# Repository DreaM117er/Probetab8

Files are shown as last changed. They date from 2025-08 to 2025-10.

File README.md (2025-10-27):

# Probetab8

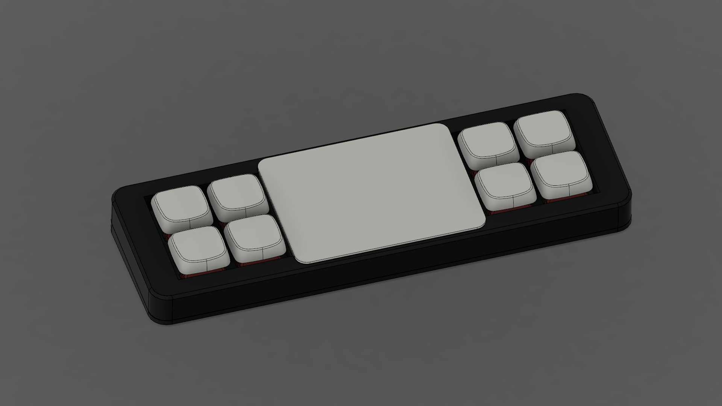
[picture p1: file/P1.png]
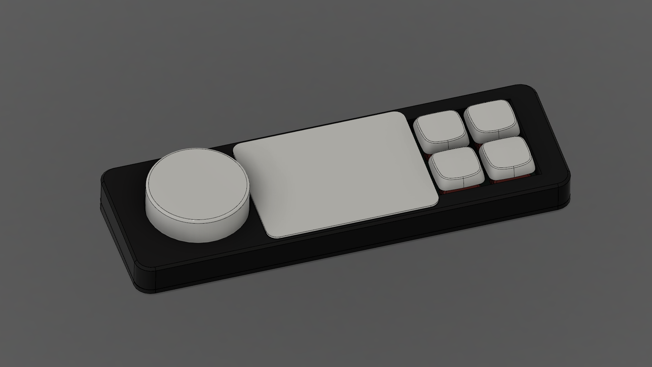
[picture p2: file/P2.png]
|||
|--|--|
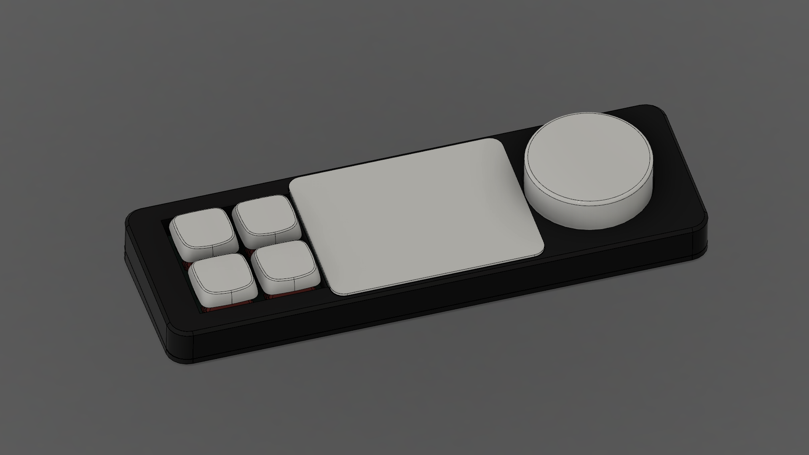
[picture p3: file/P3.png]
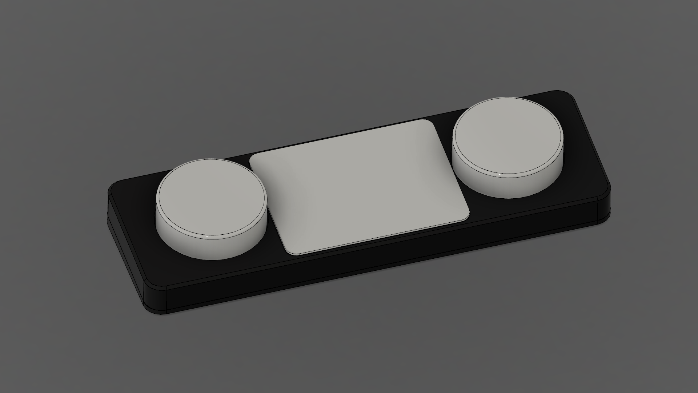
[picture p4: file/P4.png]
|||

## 說明

Probetab8是一把在設計途中不斷地向Google Gemini諮詢電路學知識的一把迷你鍵盤，是我用來進一步地學習電路學的一個巨大突破的成果。

這把鍵盤有以下幾個特點：
1. 晶片核心爲RP2040，全引腳輸出。
2. 可以燒錄RP2040 Debug Probe官方的韌體。
3. 可以按照我設計的佈局設置需要的功能：4+4顆按鍵、4按鍵+1旋鈕、2旋鈕。
4. 搭載Azoteq TPS65觸控板。
5. QMK/VIAL韌體。

## 使用材料

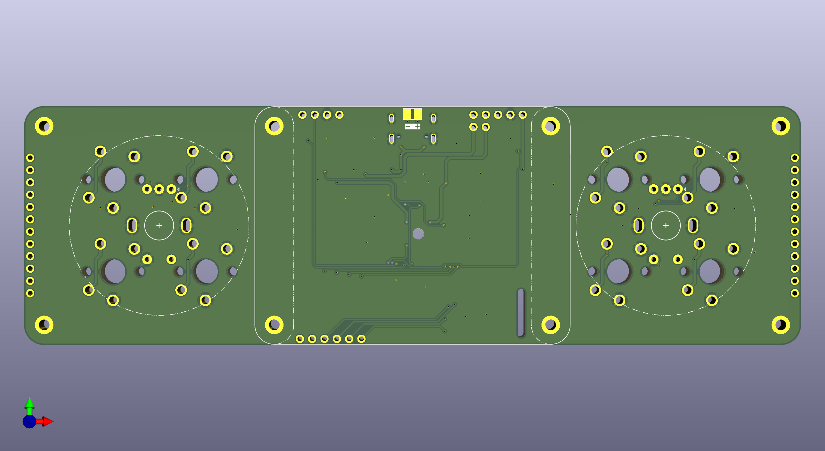
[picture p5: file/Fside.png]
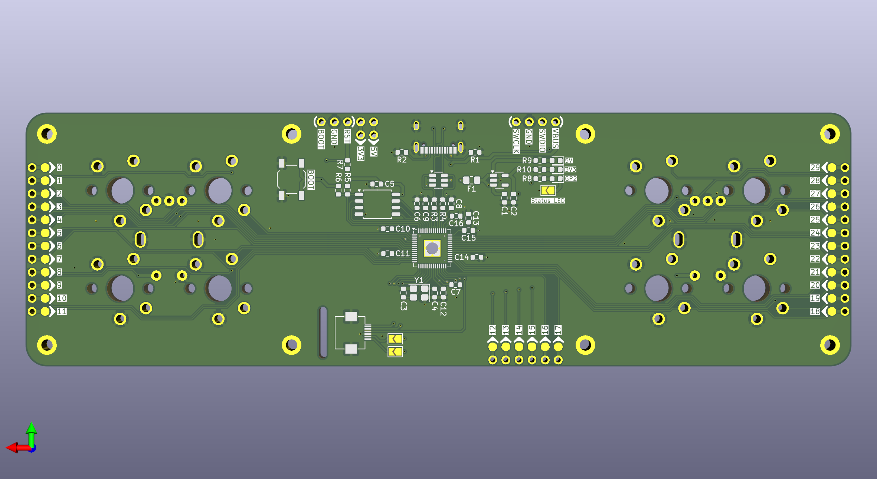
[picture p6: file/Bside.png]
|||
|--|--|

### 電子元件

|類型|名稱|數量|封裝|備註|Reference|
|--|--|--|--|--|--|
|MCU|RP2040|1|QFN-56|-|U3|
|ESD|SRV05-4|1|SOT-23-6|-|U1|
|LDO|RT9013-33GB|1|SOT-23-5|-|U2|
|QSPI|W25Q128JVS|1|SOIC-8|-|U4|
|Resonator|Crystal|1|SMD-3225-4Pin|-|Y1|
|Receptacle|USB-C|1|-|16Pin|-|
|Fuse|6V, 500mA|1|0805|-|F1|
|SW|-|1|SPST_TL3342|BOOT||
|Capacitor|1uF|4|0603|-|C1, C2, C8, C16|
|Capacitor|15pF|2|0603|-|C3, C4|
|Capacitor|100nF|10|0603|-|C5-C7, C9-C15|
|Resistor|5.1K|2|0603|-|R1, R2|
|Resistor|27R|2|0603|-|R3, R4|
|Resistor|10K|2|0603|-|R5, R7|
|Resistor|1K|1|0603|-|R6|
|Resistor|470R|2|0603|-|R8, R9|
|Resistor|220R|1|0603|-|R10|
|Module|TPS65-201A-S|1|-|-|-|
|Cable|FFC-0.5mm|1|6Pin|L: 100mm|-|
|Socket|FFC-0.5mm|1|FH12-6S-0.5SH 6Pin|-|-|
|RED|LED|3|0603|After R8-10|-|

### 機構元件

|名稱|規格|數量|備註|
|--|--|--|--|
|Screw|M2x4mm|4|扁頭|
|Screw|M2x6mm|2|扁頭|
|Screw|M2x8mm|2|扁頭|
|Case|上蓋|1|-|
|Case|下蓋|1|-|
|Feets|8x1mm|4|矽膠腳貼|

### 自由選擇

|名稱|規格|數量|備註|
|--|--|--|--|
|按鍵|Choc v1, GLP1.0-2.0|0-8|-|
|鍵帽|Choc v1, MX stem for LP|0-8|-|
|編碼器|EC-11|0-2|L: 10mm、A: 5.5-5.0mm, 半軸 D型|

## 注意事項

- 不提供CSV給大家使用，如果需要PCBA，請自行修改PCB檔案。因爲這把鍵盤屬於純手工焊接，挑戰自己的焊接技巧，成果就是你的。
- 外殼上蓋有分4種，分別應對自由選擇的元件使用，底殼通用。
- 外殼檔案及PCB檔案都開放給大家，要修正改造請按照開源相關規定，我就不再說明了。 
- 焊接的時候，特別注意預熱、加熱相關的技巧及熟悉度，以免燒壞MCU或是燙傷；還有注意環境通風。
- 關於Jumper：

    - Status LED：測試燈開關，測試沒問題可移除。
    - TPS65模組：RDY及RST，有使用這兩個引腳再焊接。

## 軟體工具

- Fusion。
- KiCAD 9.0.2。
- VScode。
- QMK、VIAL。
- Resberry官方Debug Probe韌體。

## 硬體工具

- TS-100、TS-101。
- MPH-30。
- FDM列印機。
- 萬用電表。

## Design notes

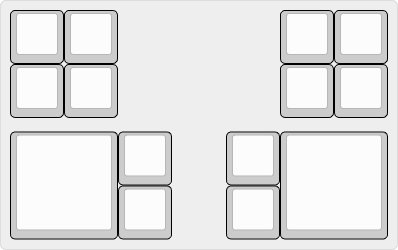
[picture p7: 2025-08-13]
file/Layout.png

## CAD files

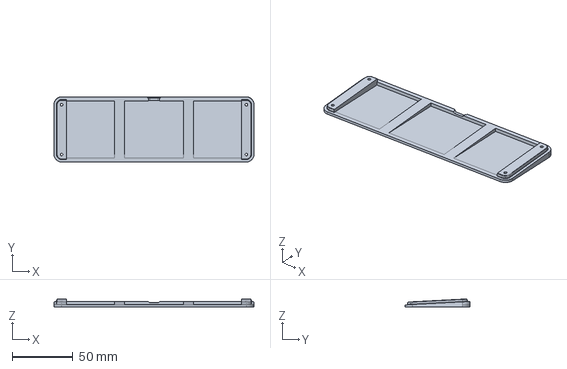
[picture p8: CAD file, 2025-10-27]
case/Bottom.step
164.4 x 53.4 x 6.69 mm

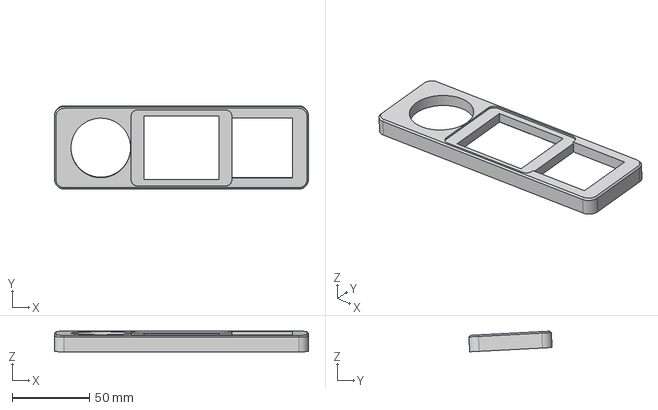
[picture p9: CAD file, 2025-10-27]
case/1x4keys.step
164.4 x 53.9 x 13.4 mm

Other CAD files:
case/4x2keys.step
case/1x1keys.step
case/4x1keys.step

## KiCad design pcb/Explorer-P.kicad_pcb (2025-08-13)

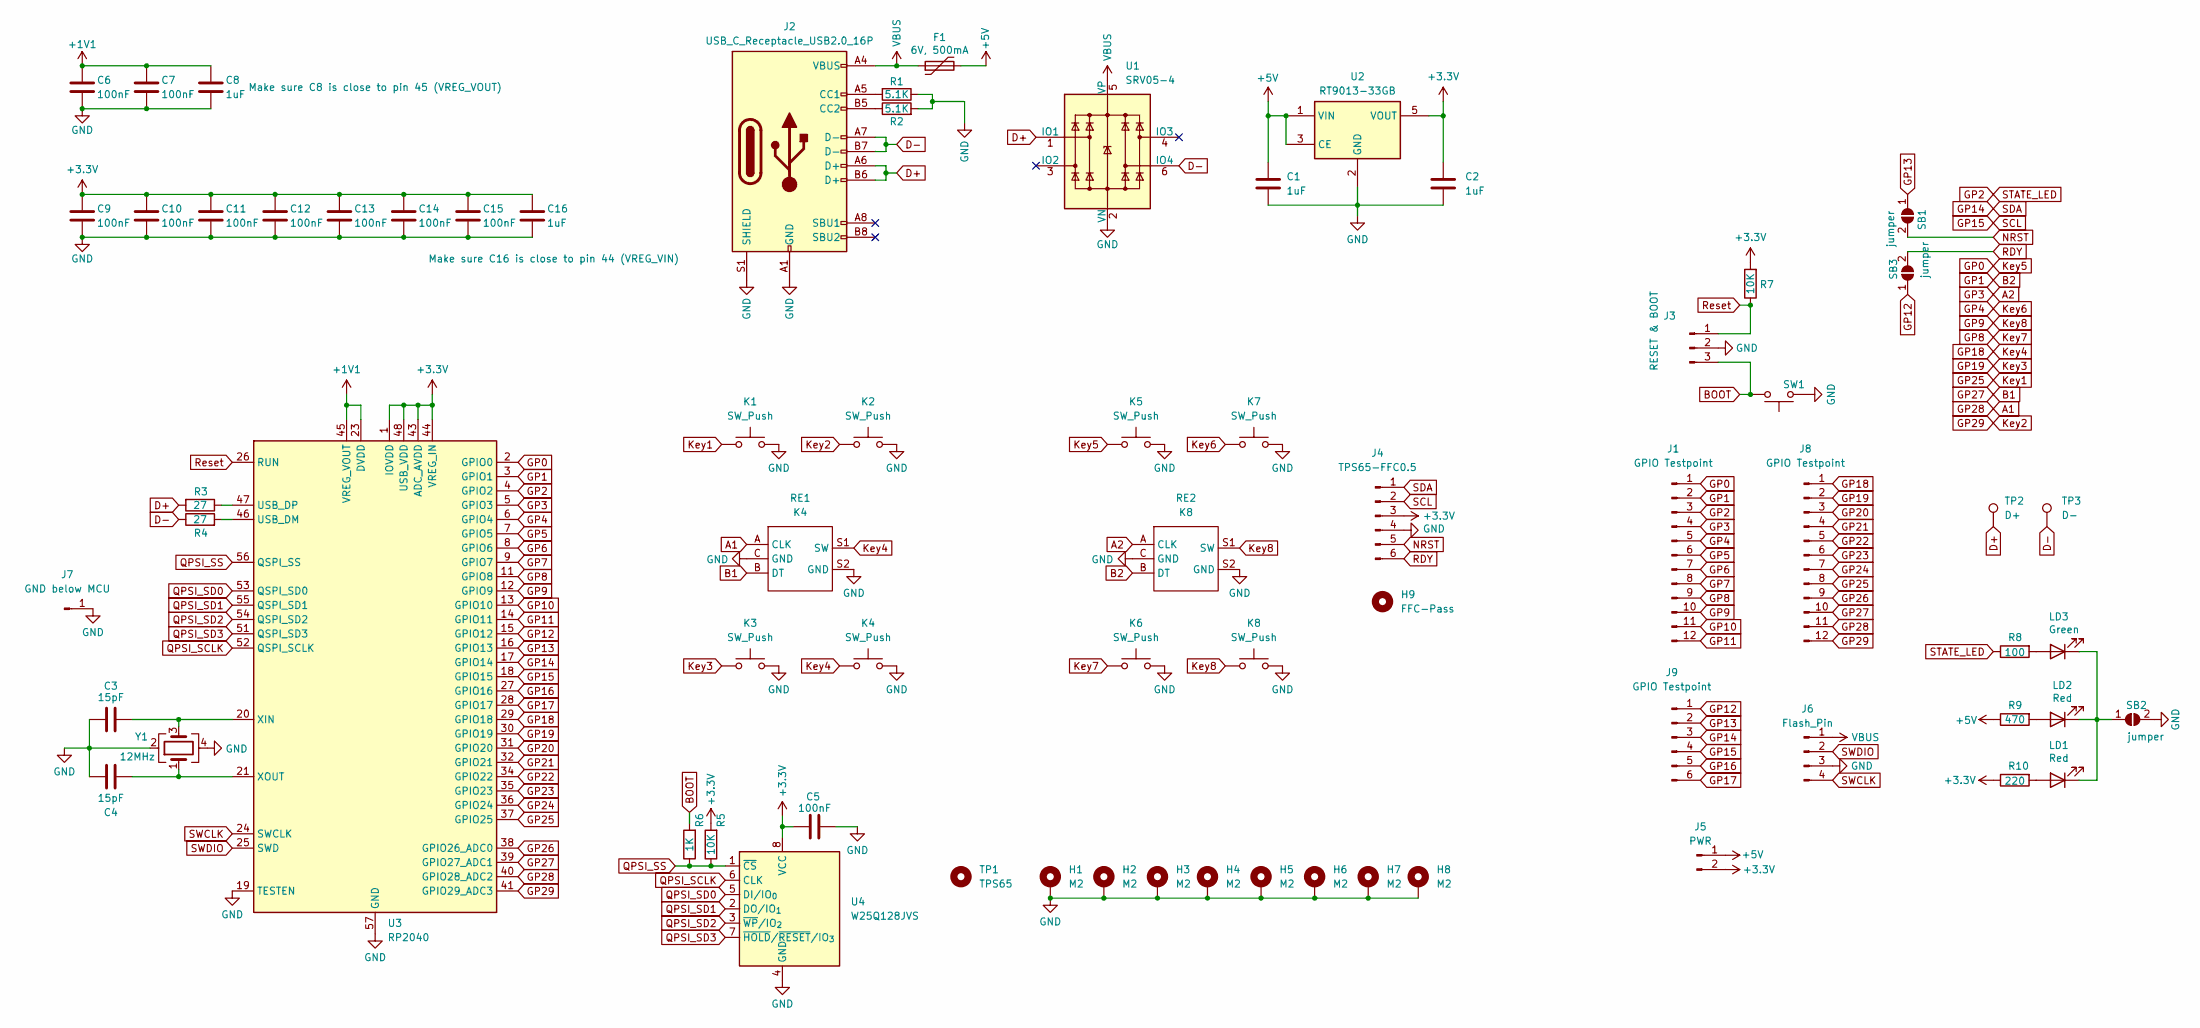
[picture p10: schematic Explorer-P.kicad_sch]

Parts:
C1, C2: 1uF; R_0603_1608Metric
C3, C4: 15pF; R_0603_1608Metric
C5: 100nF; R_0603_1608Metric
C6, C7, C9, C10, C11, C12, C13, C14, C15: 100nF; R_0603_1608Metric; MFR. Part # CL05B104KB54PNC
C8, C16: 1uF; R_0603_1608Metric; MFR. Part # CL05A105KA5NQNC
F1: 6V, 500mA; C_0805_2012Metric_Pad1.18x1.45mm_HandSolder; LCSC C269104
H1, H2, H3, H4, H5, H6, H7, H8: M2; MountingHole_2.2mm_M2_DIN965_Pad
H9: FFC-Pass; MountingHole_2.2mm_M2
J1, J8: GPIO Testpoint; Testpoint_2.54mm_01x12_1to2_Hole2Pad
J2: USB_C_Receptacle_USB2.0_16P; USB_C_Receptacle_G-Switch_GT-USB-7010ASV
J3: RESET & BOOT; PinHeader_1x03_P2.54mm_Vertical
J4: TPS65-FFC0.5; Hirose_FH12-6S-0.5SH_1x06-1MP_P0.50mm_Horizontal
J5: PWR; Testpoint_2.54mm_01x02_1to2_Hole2Pad
J6: Flash_Pin; PinHeader_1x04_P2.54mm_Vertical
J7: GND below MCU; MountingHole_2.2mm_M2_DIN965_Pad
J9: GPIO Testpoint; Testpoint_2.54mm_01x06_1to2_Hole2Pad
K1, K2, K3, K4, K5, K6, K7, K8: SW_Push; SW_Choc_GLP_KLP12_THT2
LD1, LD2: Red; LED_0603_1608Metric; MFR. Part # 19-217/GHC-YR1S2/3T; LCSC C72043
LD3: Green; LED_0603_1608Metric; MFR. Part # 19-217/GHC-YR1S2/3T; LCSC C72043
R1, R2: 5.1K; R_0603_1608Metric
R3, R4: 27; R_0603_1608Metric
R5, R7: 10K; R_0603_1608Metric
R6: 1K; R_0603_1608Metric
R8: 100; R_0603_1608Metric; MFR. Part # 0402WGF1001TCE
R9: 470; R_0603_1608Metric; MFR. Part # 0402WGF1001TCE
R10: 220; R_0603_1608Metric; MFR. Part # 0402WGF1001TCE
RE1: K4; RotaryEncoder_EC11
RE2: K8; RotaryEncoder_EC11
SB1, SB2, SB3: jumper; SolderJumper-2_P1.3mm_Open_TrianglePad1.0x1.5mm
SW1: BOOT; SW_SPST_TL3342
TP1: TPS65; Azoteq_TPS65_201A_S
TP2: D+; TestPoint_Pad_2.5x2.5mm
TP3: D-; TestPoint_Pad_2.5x2.5mm
U1: SRV05-4; SOT-23-6
U2: RT9013-33GB; SOT-23-5; LCSC C47773
U3: RP2040; QFN-56-1EP_7x7mm_P0.4mm_EP3.2x3.2mm; LCSC C2040
U4: W25Q128JVS; SOIC-8_5.3x5.3mm_P1.27mm; LCSC C97521
Y1: 12MHz; Crystal_SMD_3225-4Pin_3.2x2.5mm; LCSC C9002

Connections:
+1V1: C6.1, C7.1, C8.1, U3.23 (DVDD), U3.45 (VREG_VOUT), U3.50 (DVDD)
+3.3V: C2.1, C5.1, C9.1, C10.1, C11.1, C12.1, C13.1, C14.1, C15.1, C16.1, J4.3, J5.2, R5.2, R7.2, R10.1, U2.5 (VOUT), U3.1 (IOVDD), U3.10 (IOVDD), U3.22 (IOVDD), U3.33 (IOVDD), U3.42 (IOVDD), U3.43 (ADC_AVDD), U3.44 (VREG_IN), U3.48 (USB_VDD), U3.49 (IOVDD), U4.8 (VCC)
+5V: C1.2, F1.2, J5.1, R9.1, U2.1 (VIN), U2.3 (CE)
A1: J8.11, RE1.A (CLK), U3.40 (GPIO28_ADC2)
A2: J1.4, RE2.A (CLK), U3.5 (GPIO3)
B1: J8.10, RE1.B (DT), U3.39 (GPIO27_ADC1)
B2: J1.2, RE2.B (DT), U3.3 (GPIO1)
BOOT: J3.3, R6.2, SW1.2
D+: J2.A6 (D+), J2.B6 (D+), R3.2, TP2.1, U1.1 (IO1)
D-: J2.A7 (D-), J2.B7 (D-), R4.1, TP3.1, U1.6 (IO4)
GND: C1.1, C2.2, C3.2, C4.2, C5.2, C6.2, C7.2, C8.2, C9.2, C10.2, C11.2, C12.2, C13.2, C14.2, C15.2, C16.2, H1.1, H2.1, H3.1, H4.1, H5.1, H6.1, H7.1, H8.1, J2.A1 (GND), J2.A12 (GND), J2.B1 (GND), J2.B12 (GND), J2.S1 (SHIELD), J3.2, J4.4, J6.3, J7.1, K1.2, K2.2, K3.2, K4.2, K5.2, K6.2, K7.2, K8.2, R1.1, R2.2, RE1.C (GND), RE1.S2 (GND), RE2.C (GND), RE2.S2 (GND), SB2.2 (B), SW1.1, U1.2 (VN), U2.2 (GND), U3.19 (TESTEN), U3.57 (GND), U4.4 (GND), Y1.2, Y1.4
GP0: J1.1, K5.1, U3.2 (GPIO0)
GP2: J1.3, R8.1, U3.4 (GPIO2)
GP4: J1.5, K7.1, U3.6 (GPIO4)
GP5: J1.6, U3.7 (GPIO5)
GP6: J1.7, U3.8 (GPIO6)
GP7: J1.8, U3.9 (GPIO7)
GP8: J1.9, K6.1, U3.11 (GPIO8)
GP9: J1.10, K8.1, RE2.S1 (SW), U3.12 (GPIO9)
GP10: J1.11, U3.13 (GPIO10)
GP11: J1.12, U3.14 (GPIO11)
GP12: J9.1, SB3.1 (A), U3.15 (GPIO12)
GP13: J9.2, SB1.1 (A), U3.16 (GPIO13)
GP14: J4.1, J9.3, U3.17 (GPIO14)
GP15: J4.2, J9.4, U3.18 (GPIO15)
GP16: J9.5, U3.27 (GPIO16)
GP17: J9.6, U3.28 (GPIO17)
GP18: J8.1, K4.1, RE1.S1 (SW), U3.29 (GPIO18)
GP19: J8.2, K3.1, U3.30 (GPIO19)
GP20: J8.3, U3.31 (GPIO20)
GP21: J8.4, U3.32 (GPIO21)
GP22: J8.5, U3.34 (GPIO22)
GP23: J8.6, U3.35 (GPIO23)
GP24: J8.7, U3.36 (GPIO24)
GP25: J8.8, K1.1, U3.37 (GPIO25)
GP26: J8.9, U3.38 (GPIO26_ADC0)
GP29: J8.12, K2.1, U3.41 (GPIO29_ADC3)
NRST: J4.5, SB1.2 (B)
unnamed: J2.A5 (CC1), R1.2
unnamed: J2.B5 (CC2), R2.1
unnamed: LD1.2 (A), R10.2
unnamed: LD1.1 (K), LD2.1 (K), LD3.1 (K), SB2.1 (A)
unnamed: LD2.2 (A), R9.2
unnamed: LD3.2 (A), R8.2
unnamed: R4.2, U3.46 (USB_DM)
unnamed: R3.1, U3.47 (USB_DP)
unnamed: C3.1, U3.20 (XIN), Y1.3
unnamed: C4.1, U3.21 (XOUT), Y1.1
QPSI_SCLK: U3.52 (QSPI_SCLK), U4.6 (CLK)
QPSI_SD0: U3.53 (QSPI_SD0), U4.5 (DI/IO_{0})
QPSI_SD1: U3.55 (QSPI_SD1), U4.2 (DO/IO_{1})
QPSI_SD2: U3.54 (QSPI_SD2), U4.3 (~WP/IO_{2})
QPSI_SD3: U3.51 (QSPI_SD3), U4.7 (~HOLD/~RESET/IO_{3})
QPSI_SS: R5.1, R6.1, U3.56 (QSPI_SS), U4.1 (~CS)
RDY: J4.6, SB3.2 (B)
Reset: J3.1, R7.1, U3.26 (RUN)
SWCLK: J6.4, U3.24 (SWCLK)
SWDIO: J6.2, U3.25 (SWD)
VBUS: F1.1, J2.A4 (VBUS), J2.A9 (VBUS), J2.B4 (VBUS), J2.B9 (VBUS), J6.1, U1.5 (VP)

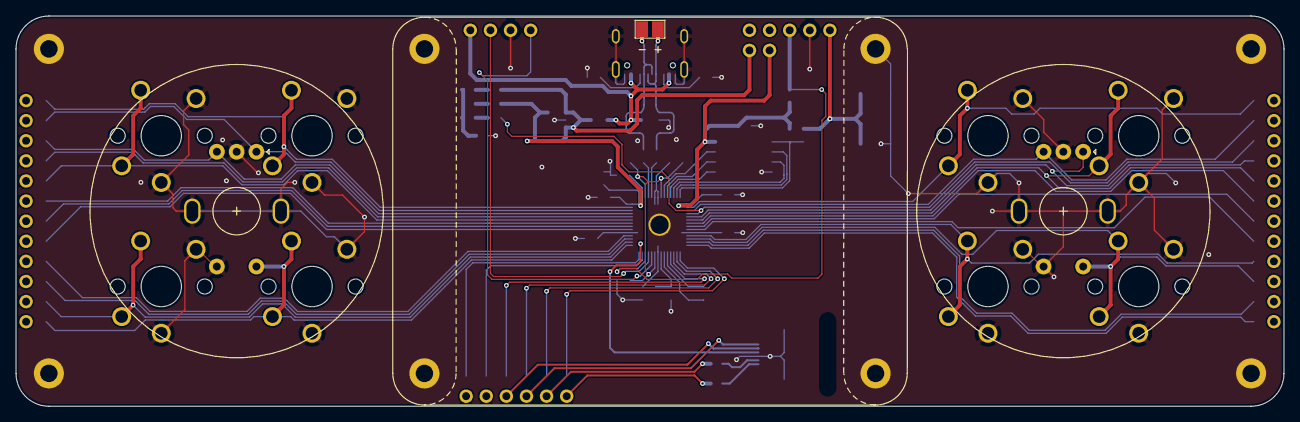
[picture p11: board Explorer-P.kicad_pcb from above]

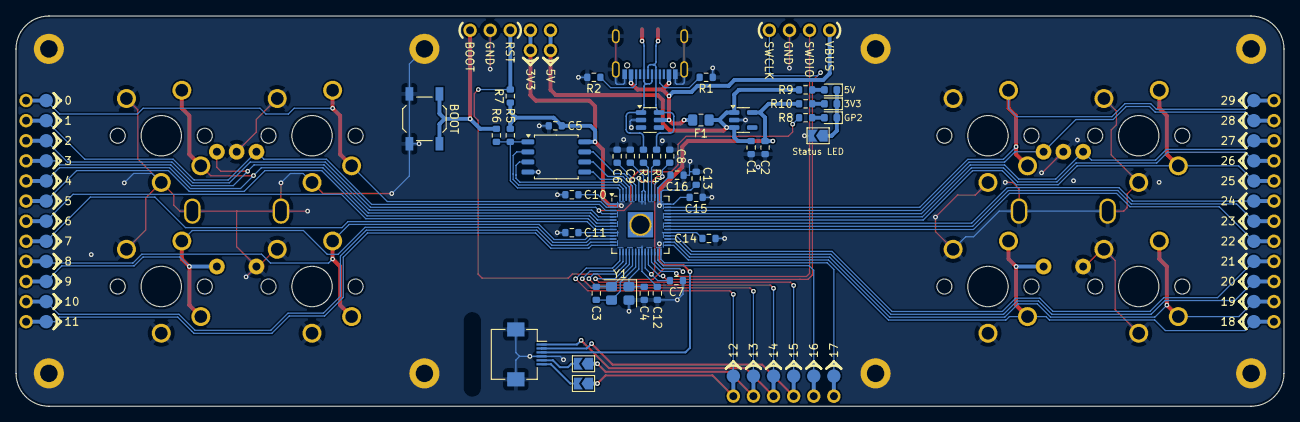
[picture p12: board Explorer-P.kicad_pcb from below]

Board: 2 copper layers, 160.2 x 49.3 mm, 70 parts (47 on the bottom side), 59 nets.

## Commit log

2025-08-15 add notes on sch file
    [Explorer-P.kicad_sch]
2025-10-27 enew readme & update case
    [1x1keys.step, 1x4keys.step, 4x1keys.step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]
